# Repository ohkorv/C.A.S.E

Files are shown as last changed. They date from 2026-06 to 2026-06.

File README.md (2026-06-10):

<h1 align="center">
  <br>
  Nytt projekt
  <br>
  C.A.S.E
  <br>
</h1>

<h4 align="center">
A sleek looking macropad
</h4>

<div align="center">

  
  
  

</div>

<div align="center">

  frontfisheye

</div>

# Project Details
C.A.S.E is a custom macropad made to fit my needs. It has 8 Baby Kangaroo Cherry MX Switches, a rotary encoder with a button usb c port and is powered by a esp32-s3.

# Repo  Structure
- `Libs/` Contains 3d models, symbols and footprints for Kicad
- `Blender/` It has the files neccesary for blender rendering.
- `Production/pcb` PCB fabrication files (Gerbers, BOM, Pick & Place)
- `Production/Case` F3d and step files of the custom case I made in Fusion 360
- `Renders/` Rendered pictures of the final product
- `Hardware/` Pcb and schematic from Kicad
- `Software/Companion App`  Companion app for controlling C.A.S.E
- `Software/MacroPad software`  Code to be put on the C.A.S.E

# Software Features
It has a easy to use companion app and is simple to setup. You simply assign actions to buttons. And have a python script running in the background.
Building the app is simple, just simply download it and download godot .net with it. Then compile it in the app. There are plenty of tutorials online if you are unsure

# Photo Gallery
frontfisheye
backfisheye







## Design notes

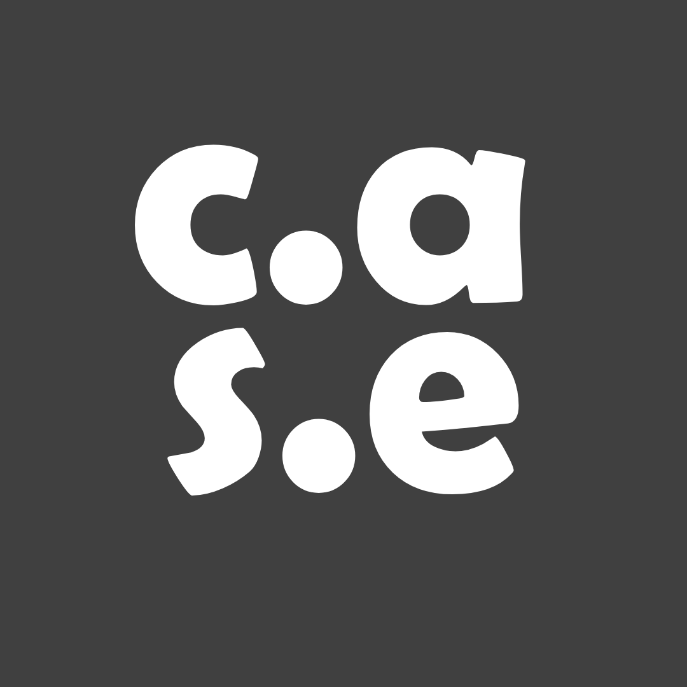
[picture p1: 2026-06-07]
Software/Companion App/images/Nytt projekt.png

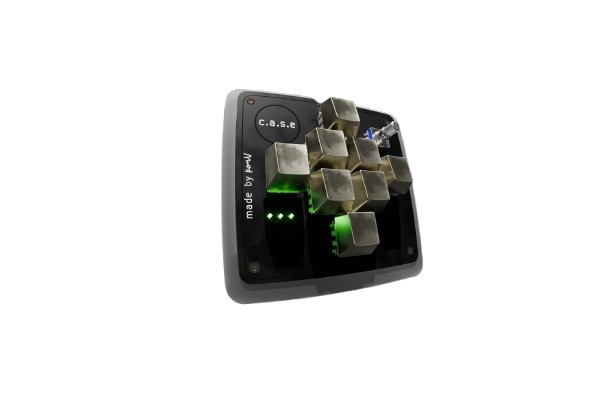
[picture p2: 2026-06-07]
Software/Companion App/images/C.A.S.E/frontfisheye-removebg-preview.png

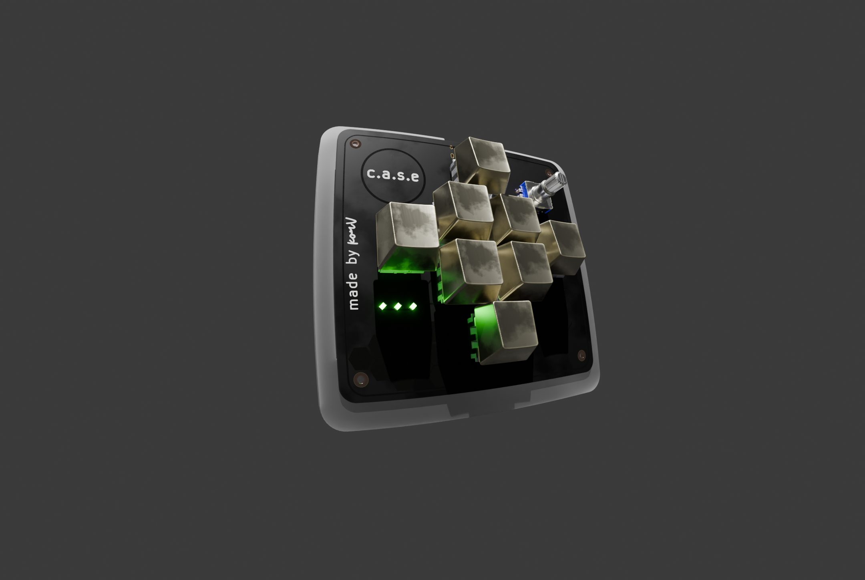
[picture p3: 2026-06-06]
Renders/frontfisheye.png

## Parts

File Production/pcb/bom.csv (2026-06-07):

Designator | Footprint | Quantity | Value | LCSC Part #
BOOT, RST | 434121025816 | 2 | SW_Push
C1, C2 | 0805 | 2 | 10uF
C6, C7 | 0805 | 2 | 0.1uF
D1 | 0805 | 1 | RED
D2, D3 | 0805 | 2 | green
J1 | SHENZHEN-CHUANGQIN-TECHNOLOGY_CQ-USB-C16PSMT01 | 1 | CQ-USB-C16PSMT01
R1, R2 | 0805 | 2 | 5.1k
R10, R11, R12 | 0805 | 3 | 150
R6, R7 | 0805 | 2 | 10k
SW1, SW2, SW3, SW4, SW5, SW6, SW7, SW8 | SW_Cherry_MX_1.00u_PCB | 8 | SW_Push
SW13 | RotaryEncoder_Alps_EC11E-Switch_Vertical_H20mm | 1 | RotaryEncoder_Switch
U1 | SOT230P700X180-4N | 1 | TLV1117-33
X1 | ESP32S3WROOM1N8R2 | 1 | ESP32-S3-WROOM-1-N16R8

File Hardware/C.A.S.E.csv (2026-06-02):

Id | Designator | Footprint | Quantity | Designation | Supplier and ref
1 | boot1, rst1 | SW_PTS645SL43SMTR92LFS | 2 | SW_Push
2 | C1, C5 | C_0805_2012Metric | 2 | 10uF
3 | C2, C3 | LED_0805_2012Metric | 2 | 4.7uF
4 | C4 | C_1206_3216Metric | 1 | 1uF
5 | C6, C7 | C_0805_2012Metric | 2 | 0.1uF
6 | J1 | SHENZHEN-CHUANGQIN-TECHNOLOGY_CQ-USB-C16PSMT01 | 1 | CQ-USB-C16PSMT01
7 | J2 | CONN_S2B-PH-K-S_JST | 1 | Conn_01x02_Pin
8 | J3 | PinHeader_2x04_P2.54mm_Vertical | 1 | Conn_02x04_Top_Bottom
9 | R1, R2 | R_1206_3216Metric | 2 | 5.1k
10 | R3 | R_0805_2012Metric | 1 | 3.3k
11 | R4 | R_1206_3216Metric | 1 | 1.8k
12 | R5, R6, R7 | R_0805_2012Metric | 3 | 10k
13 | R8, R9 | R_1206_3216Metric | 2 | 100k
14 | SW1, SW2, SW3, SW4, SW5, SW6, SW7, SW8 | SW_Cherry_MX_1.00u_PCB | 8 | SW_Push
15 | SW12 | SW_CK_JS202011AQN_DPDT_Angled | 1 | SW_SPDT
16 | SW13 | RotaryEncoder_Alps_EC11E-Switch_Vertical_H20mm | 1 | RotaryEncoder_Switch
17 | U2 | SOT95P285X140-5N | 1 | AP2112K-3.3
18 | U3 | RGT16_1P7X1P7 | 1 | BQ24072TRGTR
19 | X1 | ESP32S3WROOM1N8R2 | 1 | ESP32-S3-WROOM-1-N16R8

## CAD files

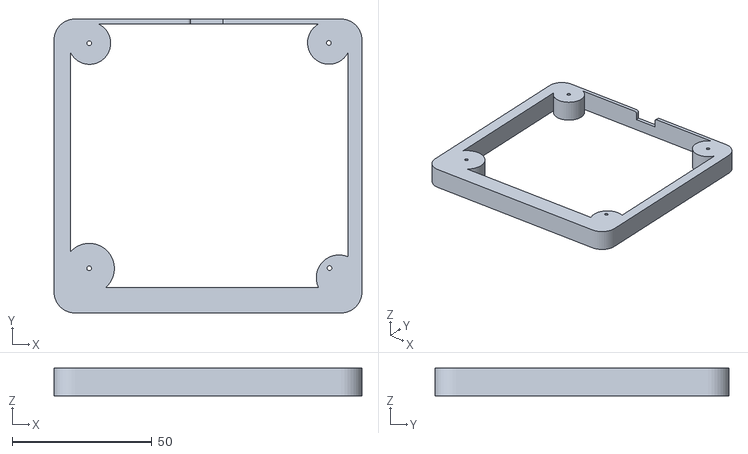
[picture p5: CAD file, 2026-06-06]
Blender/C.A.S.E case.stl
110.0 x 105.0 x 10.0

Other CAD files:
Production/Case/C.A.S.E case.step
Blender/blender.blend
Production/Case/case.f3d

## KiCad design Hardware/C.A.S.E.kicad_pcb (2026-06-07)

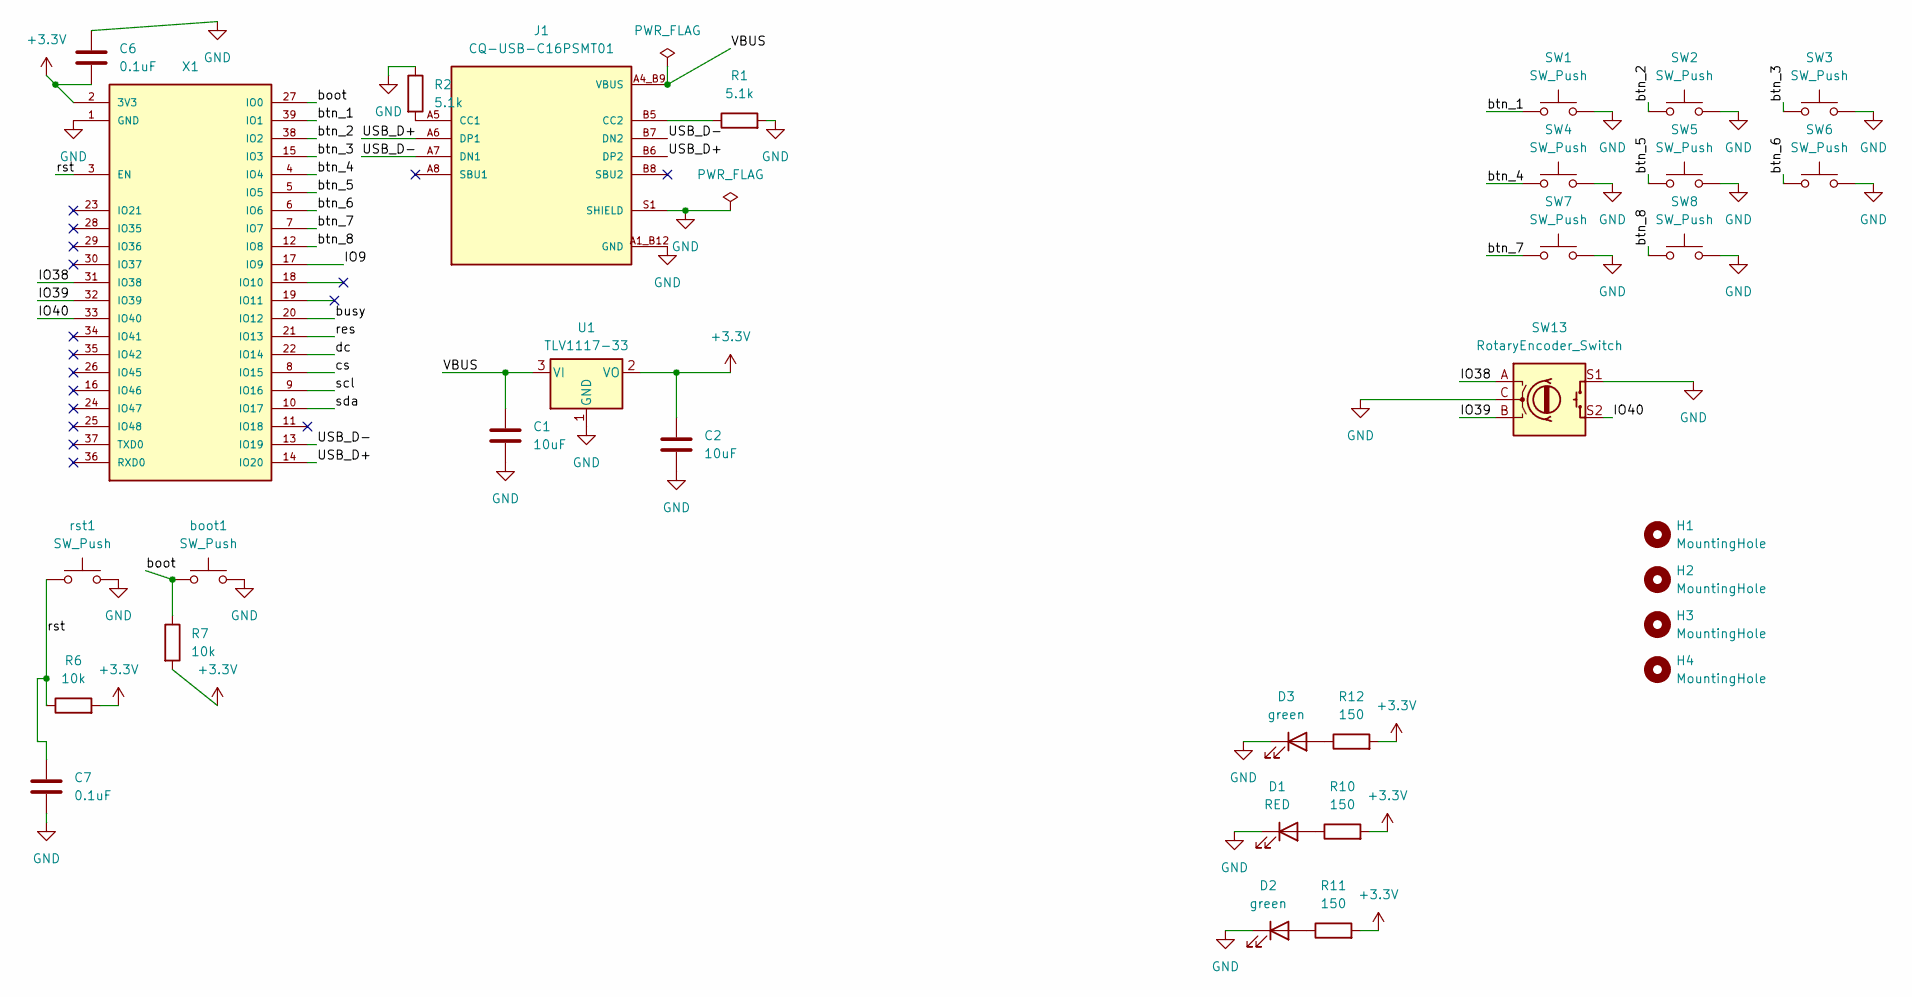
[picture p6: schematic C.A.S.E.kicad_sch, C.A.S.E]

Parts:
C1, C2: 10uF; C_0805_2012Metric
C6, C7: 0.1uF; C_0805_2012Metric
D1: RED; LED_0805_2012Metric
D2, D3: green; LED_0805_2012Metric
H1, H2, H3, H4: MountingHole; MountingHole_2.2mm_M2_Pad
J1: CQ-USB-C16PSMT01; SHENZHEN-CHUANGQIN-TECHNOLOGY_CQ-USB-C16PSMT01; PARTREV A
R1, R2: 5.1k; R_0805_2012Metric
R6, R7: 10k; R_0805_2012Metric
R10, R11, R12: 150; R_0805_2012Metric
SW1, SW2, SW3, SW4, SW5, SW6, SW7, SW8: SW_Push; SW_Cherry_MX_1.00u_PCB
SW13: RotaryEncoder_Switch; RotaryEncoder_Alps_EC11E-Switch_Vertical_H20mm
U1: TLV1117-33; SOT230P700X180-4N
X1: ESP32-S3-WROOM-1-N16R8; ESP32S3WROOM1N8R2; MANUFACTURER_PART_NUMBER ESP32-S3-WROOM-1-N16R8
boot1: SW_Push; 434121025816
rst1: SW_Push; 434121025816

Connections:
+3.3V: C2.1, C6.2, R6.2, R7.2, R10.2, R11.2, R12.2, U1.2 (VO), X1.2 (3V3)
/IO9: X1.17 (IO9)
/IO38: SW13.A, X1.31 (IO38)
/IO39: SW13.B, X1.32 (IO39)
/IO40: SW13.S2, X1.33 (IO40)
/USB_D+: J1.A6 (DP1), J1.B6 (DP2), X1.14 (IO20)
/USB_D-: J1.A7 (DN1), J1.B7 (DN2), X1.13 (IO19)
/boot: R7.1, X1.27 (IO0), boot1.1; also elsewhere on the board
/btn_1: SW1.1, X1.39 (IO1)
/btn_2: SW2.1, X1.38 (IO2)
/btn_3: SW3.1, X1.15 (IO3)
/btn_4: SW4.1, X1.4 (IO4)
/btn_5: SW5.1, X1.5 (IO5)
/btn_6: SW6.1, X1.6 (IO6)
/btn_7: SW7.1, X1.7 (IO7)
/btn_8: SW8.1, X1.12 (IO8)
/busy: X1.20 (IO12)
/cs: X1.8 (IO15)
/dc: X1.22 (IO14)
/res: X1.21 (IO13)
/rst: C7.2, R6.1, X1.3 (EN), rst1.1; also elsewhere on the board
/scl: X1.9 (IO16)
/sda: X1.10 (IO17)
GND: C1.2, C2.2, C6.1, C7.1, D1.1 (K), D2.1 (K), D3.1 (K), J1.A1_B12 (GND), J1.B1_A12 (GND), J1.S1 (SHIELD), J1.S2 (SHIELD), J1.S3 (SHIELD), J1.S4 (SHIELD), R1.2, R2.1, SW1.2, SW2.2, SW3.2, SW4.2, SW5.2, SW6.2, SW7.2, SW8.2, SW13.C, SW13.S1, U1.1 (GND), X1.1 (GND), X1.40 (GND), X1.41 (GND), X1.42 (GND), X1.43 (GND), X1.44 (GND), X1.45 (GND), X1.46 (GND), X1.47 (GND), X1.48 (GND), X1.49 (GND), boot1.2, rst1.2; also elsewhere on the board
unnamed: D1.2 (A), R10.1
unnamed: D2.2 (A), R11.1
unnamed: D3.2 (A), R12.1
unnamed: J1.A5 (CC1), R2.2
unnamed: J1.B5 (CC2), R1.1
VBUS: C1.1, J1.A4_B9 (VBUS), J1.B4_A9 (VBUS), U1.3 (VI)

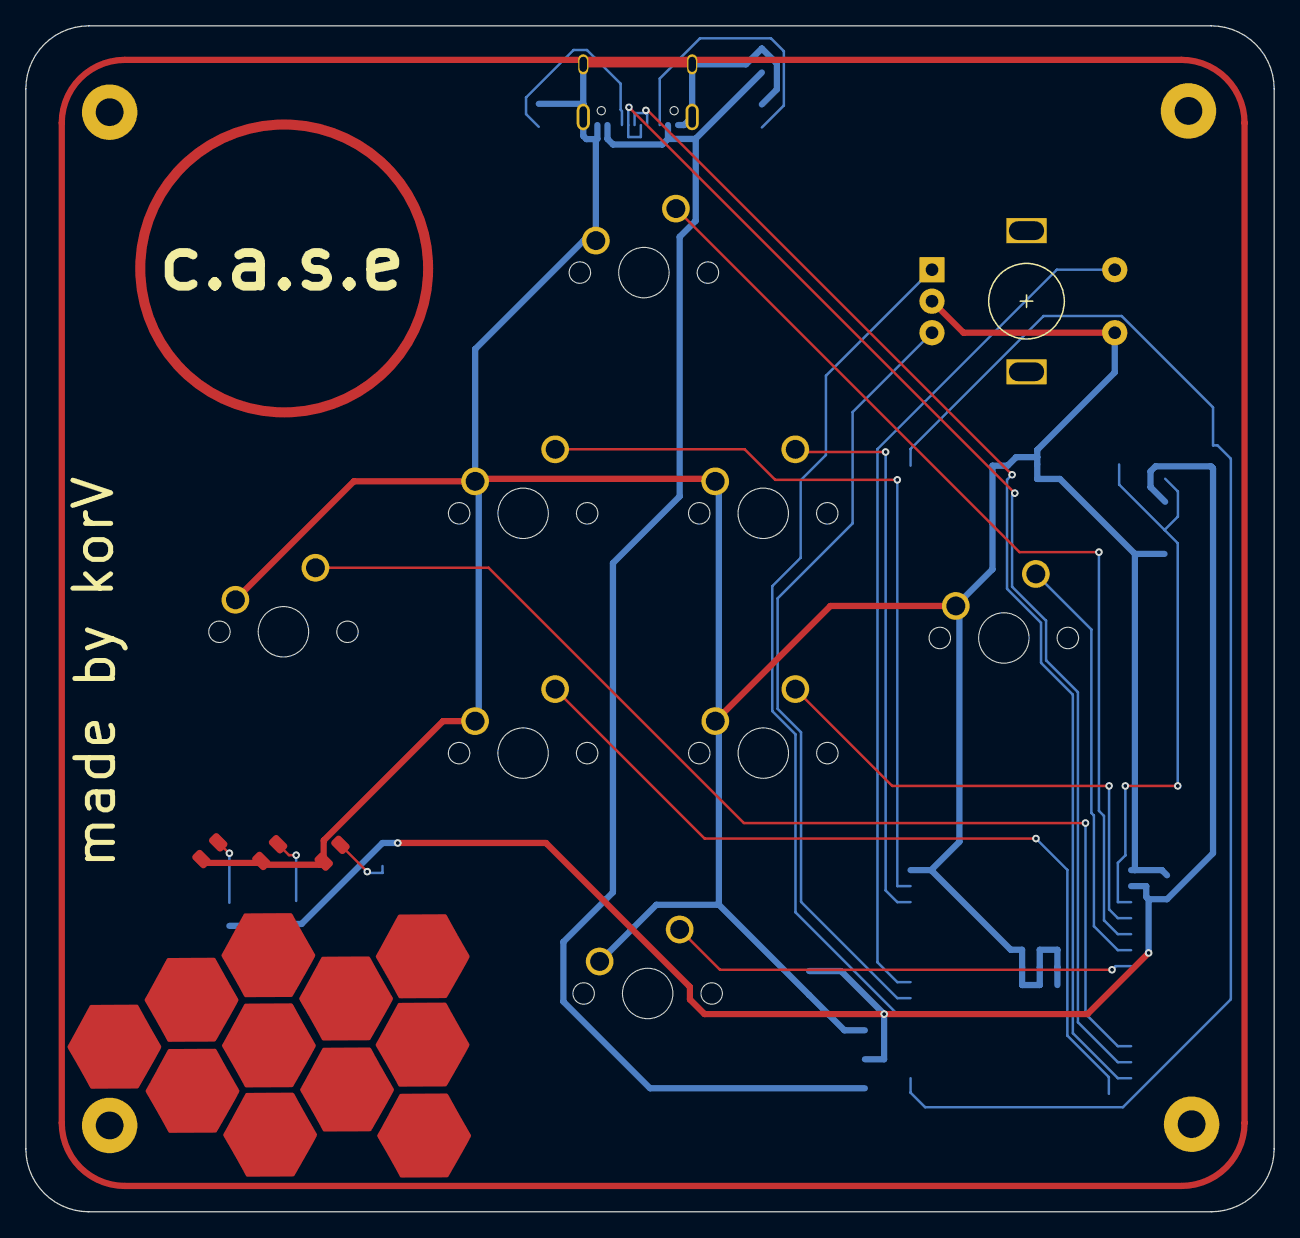
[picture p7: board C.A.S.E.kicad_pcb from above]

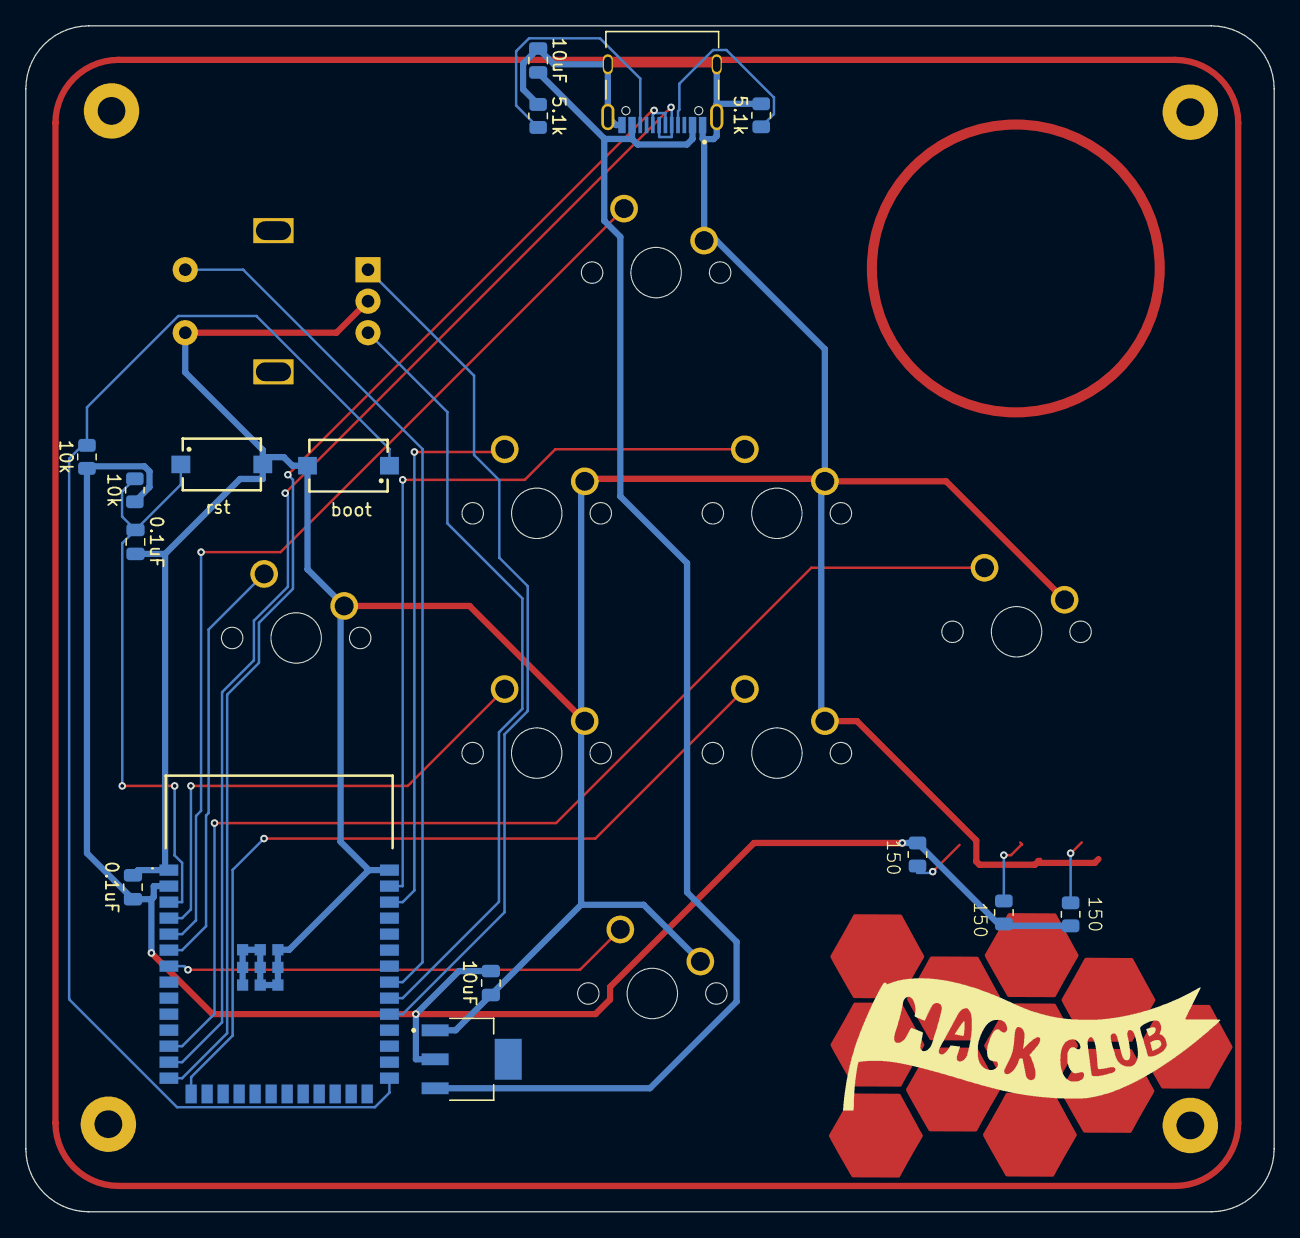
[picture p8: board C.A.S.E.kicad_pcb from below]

Board: 2 copper layers, 99.0 x 94.1 mm, 32 parts (16 on the bottom side), 23 nets.

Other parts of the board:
boot: SW_Push; 434121025816
rst: SW_Push; 434121025816

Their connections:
/boot: boot.1; also elsewhere on the board
/rst: rst.1; also elsewhere on the board
GND: boot.2, rst.2; also elsewhere on the board

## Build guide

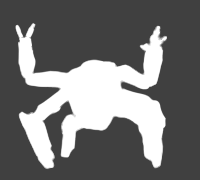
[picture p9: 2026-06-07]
Software/Companion App/images/11644151_-rocky-project-hail-mary-stl-file-for-3d-printing--removebg-preview.png

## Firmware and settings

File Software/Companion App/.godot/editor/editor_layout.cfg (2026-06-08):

[docks]

dock_3_selected_tab_idx=0
dock_4_selected_tab_idx=0
dock_5_selected_tab_idx=0
dock_floating={}
dock_closed=[]
dock_split_2=0
dock_split_3=0
dock_hsplit_1=0
dock_hsplit_2=280
dock_hsplit_3=-288
dock_hsplit_4=0
dock_9_selected_tab_idx=0
dock_3="Scene,Import"
dock_4="FileSystem,History"
dock_5="Inspector,Signals,Groups"
dock_9="Output,Debugger,Audio,Animation,Shader Editor,MSBuild,Search Results,AnimationTree,ResourcePreloader,ShaderFile,SpriteFrames,Theme,Polygon,TileSet,TileMap,Replication,GridMap"

[docks/FileSystem]

h_split_offset=300
v_split_offset=0
display_mode=0
file_sort=0
file_list_display_mode=1
selected_paths=PackedStringArray("res://images/heroicons--play-pause-solid.png")
uncollapsed_paths=PackedStringArray("Favorites", "res://", "res://scenes/", "res://images/")

[docks/History]

include_scene=true
include_global=true

[EditorNode]

open_scenes=PackedStringArray("res://scenes/MainWindow.tscn", "res://scenes/TopBar.tscn", "res://scenes/Blurbackground.tscn")
current_scene="res://scenes/MainWindow.tscn"
bottom_panel_offsets={
"Animation": 0,
"Audio": -450,
"Debugger": -286,
"MSBuild": 0,
"Output": -271,
"Shader Editor": 0,
"Theme": 0
}
selected_default_debugger_tab_idx=0
selected_main_editor_idx=0

[EditorWindow]

screen=0
mode="maximized"
position=Vector2i(0, 29)
size=Vector2i(1152, 648)

[ScriptEditor]

open_scripts=["res://scenes/button_assigner.gd", "res://scripts/MainWindow.cs"]
selected_script="res://scenes/button_assigner.gd"
open_help=[]
script_split_offset=250
list_split_offset=0
zoom_factor=0.7142856

[GameView]

floating_window_rect=Rect2i(0, 0, 0, 0)
floating_window_screen=-1

[ShaderEditor]

open_shaders=[]
split_offset=250
selected_shader=""
text_shader_zoom_factor=1.0

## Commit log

2026-06-02 adding more stuff
    [1x1 R1.step, AP2112K-3.3TRG1.step, C.A.S.E.csv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]
2026-06-05 changed everything
    [434121025816.step, C.A.S.E.kicad_pcb, C.A.S.E.kicad_sch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]
2026-06-06 some stuff
    [C.A.S.E case.step, C.A.S.E case.stl, blender.blend]
2026-06-07 added the companion app
    [Avenir Regular.ttf-5ebf39eeb0a869c2fa7caa55189f6ead.fontdata-folding-c67ceb3f4398762fd454f690b83cde5b.cfg, Avenir Regular.ttf-fba0c139a82f703a7e2fafbc8323d813.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]
2026-06-07 Insert project image in README
    Add project image to README with center alignment
2026-06-07 cleaned up the repo
    [Avenir Regular.ttf-5ebf39eeb0a869c2fa7caa55189f6ead.fontdata-folding-c67ceb3f4398762fd454f690b83cde5b.cfg, Avenir Regular.ttf-fba0c139a82f703a7e2fafbc8323d813.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]
2026-06-08 companion app fixes
    [MainWindow.tscn-editstate-8802af2077d07528ccf7d1e851cd4b0e.cfg, MainWindow.tscn-folding-8802af2077d07528ccf7d1e851cd4b0e.cfg, button_assigner.gd-folding-c237bd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]

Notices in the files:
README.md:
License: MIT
